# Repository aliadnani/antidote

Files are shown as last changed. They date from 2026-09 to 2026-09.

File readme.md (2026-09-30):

antidote logo

Budget neural amp modelling on a Radxa Cubie A7Z.

---
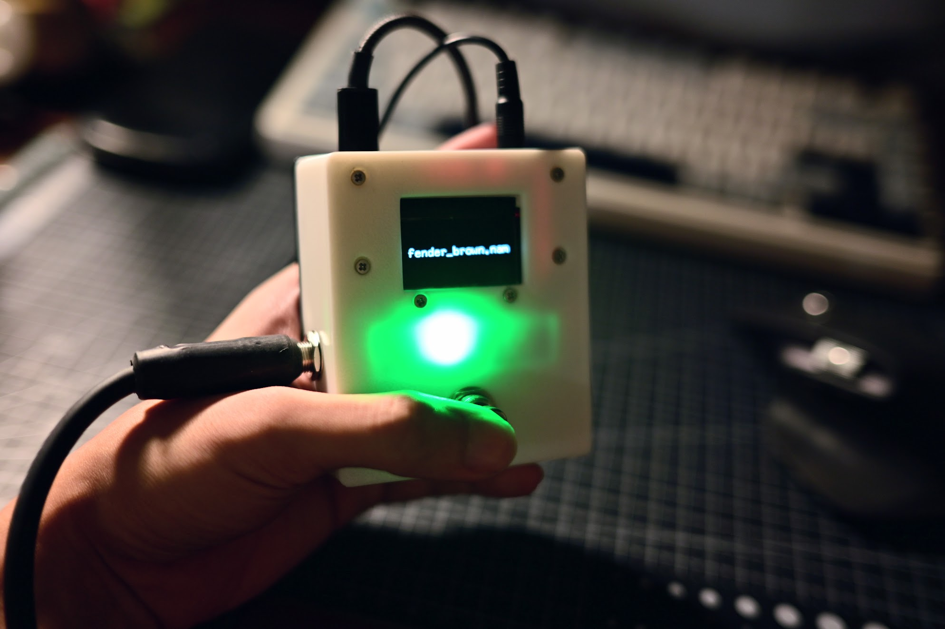
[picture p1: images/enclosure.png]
enclosure


[(sloppy demo video)](https://www.youtube.com/shorts/qqARMGN2HPs)

## What this project does

Neural Amp Modeler (NAM) uses neural networks to model guitar amplifiers from recorded input/output pairs, then reproduces their response on live guitar audio. I want to make a standalone guitar pedal for it.

Rust firmware runs on a Radxa Cubie A7Z Linux SBC. It manages real-time audio capture and playback, including the hot loop that processes each buffer, wraps NAM A2’s C++ DSP library via FFI, and coordinates model loading and the pedal’s peripherals. A custom audio board provides instrument-level input and output.

The end goal is a budget, performant, standalone NAM pedal targetting buffers processed in under 10 ms (ideally under 5 ms) - essentially the threshold for human auditory latency perception.

## This repo

- `src/`: Rust firmware for audio processing, NAM A2 FFI, model loading, and pedal controls.
- `hardware/`: Schematics and PCB design files for the audio board + associated Linux device tree overlays

**Please see this repository as more of a reference design for what's possible and how such a pedal could be built, rather than a polished product.**

## Hardware setup

1. Source a Radxa Cubie A7Z
   - Note: other similar SBCs (like the Pi Zero/OrangePis/etc.) likely **will not work** due to different GPIO header pinouts
2. Have the audio board fabricated with all components populated.
3. Connect the audio board to the SBC via the 40-pin GPIO header.
4. Connect other peripherals to the audio board. In my case, I connected (and built my firmware around):
   - 3.5mm headphone jack for phones
   - 6.35mm TS input for guitar
   - 6.35mm TS output for amp
   - A single footswitch
   - An I2C OLED display (SH1106)
   - A WS2812B LED strip

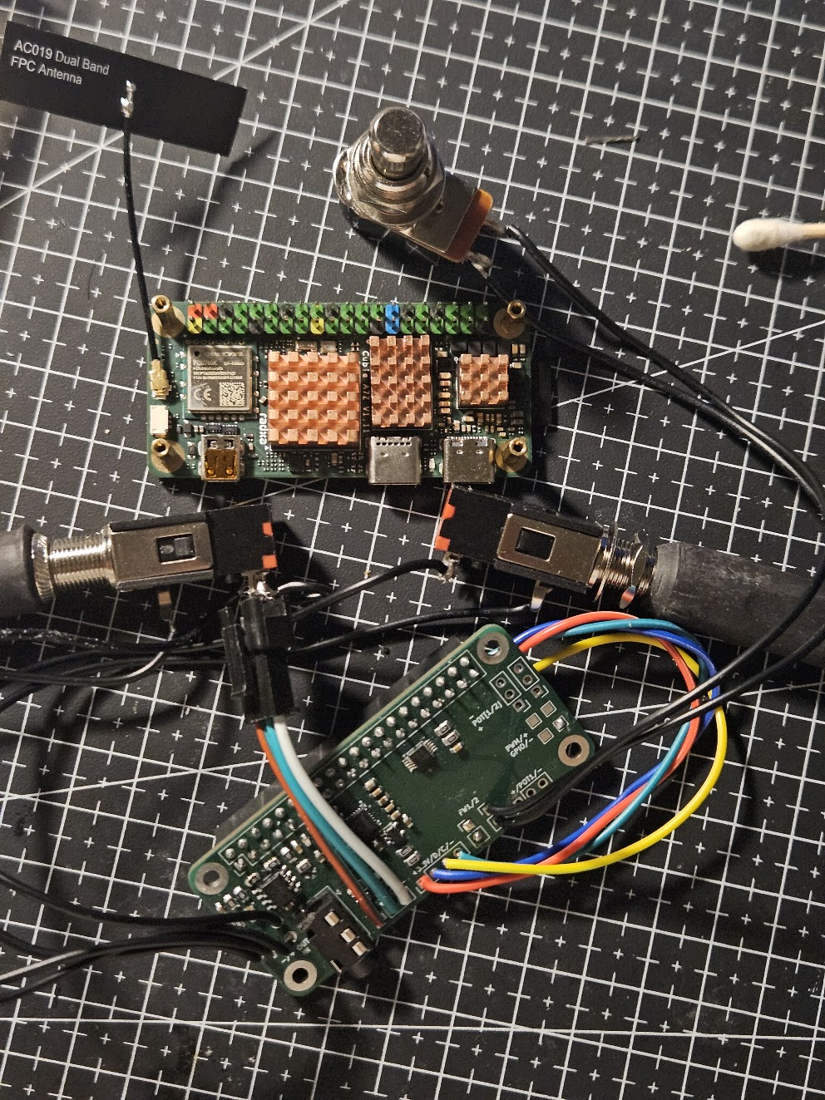
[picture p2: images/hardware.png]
hardware setup


## Firmware setup

1. Flash the SBC with Linux. Official Radxa images or community Armbian images should work fine.
2. Compile and load the driver for the audio board's codec (TAC5112).
   - See the [TI git repository](https://git.ti.com/cgit/lpaa-android-drivers/tac5x1x-linux-driver/?h=tac5x1x_driver) for the source. Check out a branch or tag compatible with your kernel version.
   - Run `make`, then load the kernel module with `insmod` or `modprobe`.
3. Compile and load the device tree overlay for the audio board.
   - The source is `./hardware/tac5112_i2c_i2s_overlay.dts`. Compile it with `dtc` into a `.dtbo` file, then load it via `rsetup`.
4. Configure the codec's ADC, DAC, and capture/playback paths if needed. These commands may be needed:
   ```sh
   sudo amixer -c 0 cset name='ASI_RX_CH1_EN Switch' on
   sudo amixer -c 0 cset name='OUT1x Source' 'DAC Input'
   sudo amixer -c 0 cset name='OUT1x Config' 'Pseudo differential with OUTxM as VCOM'
   sudo amixer -c 0 cset name='OUT1x Driver' 'Headphone'

   sudo amixer -c 0 cset name='ASI_RX_CH2_EN Switch' on
   sudo amixer -c 0 cset name='OUT2x Source' 'DAC Input'
   sudo amixer -c 0 cset name='OUT2x Config' 'Mono Single-ended at OUTxP only'
   sudo amixer -c 0 cset name='OUT2x Driver' 'Line-out'

   sudo amixer -c 0 cset name='ADC1 Config' 'Single-ended'
   sudo amixer -c 0 cset name='ADC1 Common-mode Tolerance' 'AC Coupled with 100mVpp'
   sudo amixer -c 0 cset name='ADC1 Full-Scale' '2/10-VRMS'
   sudo amixer -c 0 cset name='ASI_TX_CH1 Slot' 'Slot0'
   sudo amixer -c 0 cset name='ASI_TX_CH1_EN Capture Switch' on
   sudo amixer -c 0 cset name='ADC1 Digital Capture Volume' 161

   sudo amixer -c 0 cset name='IN1 Source Mux' 'Analog'
   sudo amixer -c 0 cset name='IN2 Source Mux' 'Analog'
   ```
5. Pull in the dependencies, then build the firmware in release mode on the SBC or cross-compile it on a host:
   ```sh
   git submodule update --init --recursive
   cargo build --release
   ```
6. Run the firmware in release mode, passing the directory containing your `.nam` models. If omitted, it uses `resources/`:
   ```sh
   ./target/release/antidote /path/to/nam/files
   # Or:
   cargo run --release -- /path/to/nam/files
   ```

   ```text
   2026-09-25T16:57:33.860341Z  INFO antidote: Starting Antidote.
   2026-09-25T16:57:33.880659Z  INFO antidote::modeller: Loaded NAM A2 model. model_path=resources/fender_brown.nam
   2026-09-25T16:57:33.880875Z  INFO antidote: Starting CPAL.
   2026-09-25T16:57:33.989547Z  INFO antidote: Playing back audio for 500 seconds.
   2026-09-25T16:57:34.898597Z  INFO antidote::audio: Audio errors input_drops=0 output_drops=0 output_underruns=320
   2026-09-25T16:57:35.898842Z  INFO antidote::audio: Audio errors input_drops=0 output_drops=0 output_underruns=320
   2026-09-25T16:57:36.899102Z  INFO antidote::audio: Audio errors input_drops=0 output_drops=0 output_underruns=320
   ...
   ```

## Polishing touches

Once everything is working, some things you can do to make the pedal more usable:

- Add a `systemd` service to run the firmware on boot

### Optimizations

- Disable all unnecessary kernel modules to reduce boot time
  - Stock boots in around ~20 seconds which is actually pretty good - but you can cut another 5-10
- If using a `6.12+` kernel, you can use the play with the `PREEMPT_RT` to reduce latency
- Play around with `mlockall` and `threadirqs`, core pinning/isolation. You can push buffer sizes to around ~24 this way yielding a theorical round-trip latency of ~2ms. 

## Some design goals/notes:

In principle, this project actually builds an entire hardware platform for *any* real-time guitar processing application for Linux SBCs. You can just as easily swap out the the firmware for another that runs say LV2/VST plugins. Though the main focus for this project is a standalone NAM pedal.

---

Built on top of:

- [NAM A2 Source Code](https://github.com/sdatkinson/NeuralAmpModelerCore)
- [NAM A2 Reference](https://www.tone3000.com/guides/nam-a2-the-complete-guide)

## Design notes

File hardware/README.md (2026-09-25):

# Hardware

This directory contains hardware-related files for the Antidote project, including schematics, PCB layouts, and other stuff.

So far we have:
- `antidote-audio-board/`: KiCAD project for the Antidote audio board.
  - See `antidote-audio-board/schematic.pdf` for a PDF of the schematic.
- `tac5112_i2c_i2s_overlay.dts`: The overlay so we can actually bring up the TAC5112 audio codec on our Radxa Cubie A7Z.

## Audio Bring Up on the Radxa Cubie A7Z

Assuming:
- The TAC5112 (daughter-board) is connected via the GPIO headers
- The TAC5112 drivers are compiled and loaded as a module
  - For kernel: 5.15: https://git.ti.com/cgit/lpaa-android-drivers/tac5x1x-linux-driver/log/?h=tac5x1x_driver_k5.15
- The device overlay is compiled and loaded (e.g. via rsetup)

**To play a test tone:**
```bash
# Left channel (for mono headphones - same signal bridged at T/R pins)
# Not sure if `sudo` is needed to be honest
sudo amixer -c 0 cset name='ASI_RX_CH1_EN Switch' on
sudo amixer -c 0 cset name='OUT1x Source' 'DAC Input'
sudo amixer -c 0 cset name='OUT1x Config' 'Pseudo differential with OUTxM as VCOM'
sudo amixer -c 0 cset name='OUT1x Driver' 'Headphone'

# Right channel for instrument line out
sudo amixer -c 0 cset name='ASI_RX_CH2_EN Switch' on
sudo amixer -c 0 cset name='OUT2x Source' 'DAC Input'
sudo amixer -c 0 cset name='OUT2x Config' 'Mono Single-ended at OUTxP only'
sudo amixer -c 0 cset name='OUT2x Driver' 'Line-out'

speaker-test -D hw:0,0 -c 2 -r 48000 -F S32_LE -t sine -f 440
```

**To record audio (+generate spectrogram and log metrics):**
```bash
sudo amixer -c 0 cset name='ADC1 Config' 'Single-ended'
sudo amixer -c 0 cset name='ADC1 Common-mode Tolerance' 'AC Coupled with 100mVpp'
sudo amixer -c 0 cset name='ADC1 Full-Scale' '2/10-VRMS'
sudo amixer -c 0 cset name='ASI_TX_CH1 Slot' 'Slot0'
sudo amixer -c 0 cset name='ASI_TX_CH1_EN Capture Switch' on
sudo amixer -c 0 cset name='ADC1 Digital Capture Volume' 161

sudo amixer -c 0 cset name='IN1 Source Mux' 'Analog'
sudo amixer -c 0 cset name='IN2 Source Mux' 'Analog'

arecord -D hw:0,0 -c 2 -f S32_LE -r 48000 -d 5 retest.wav
sox retest.wav -n stat
sox retest.wav -n spectrogram -o retest_spectro.png
```

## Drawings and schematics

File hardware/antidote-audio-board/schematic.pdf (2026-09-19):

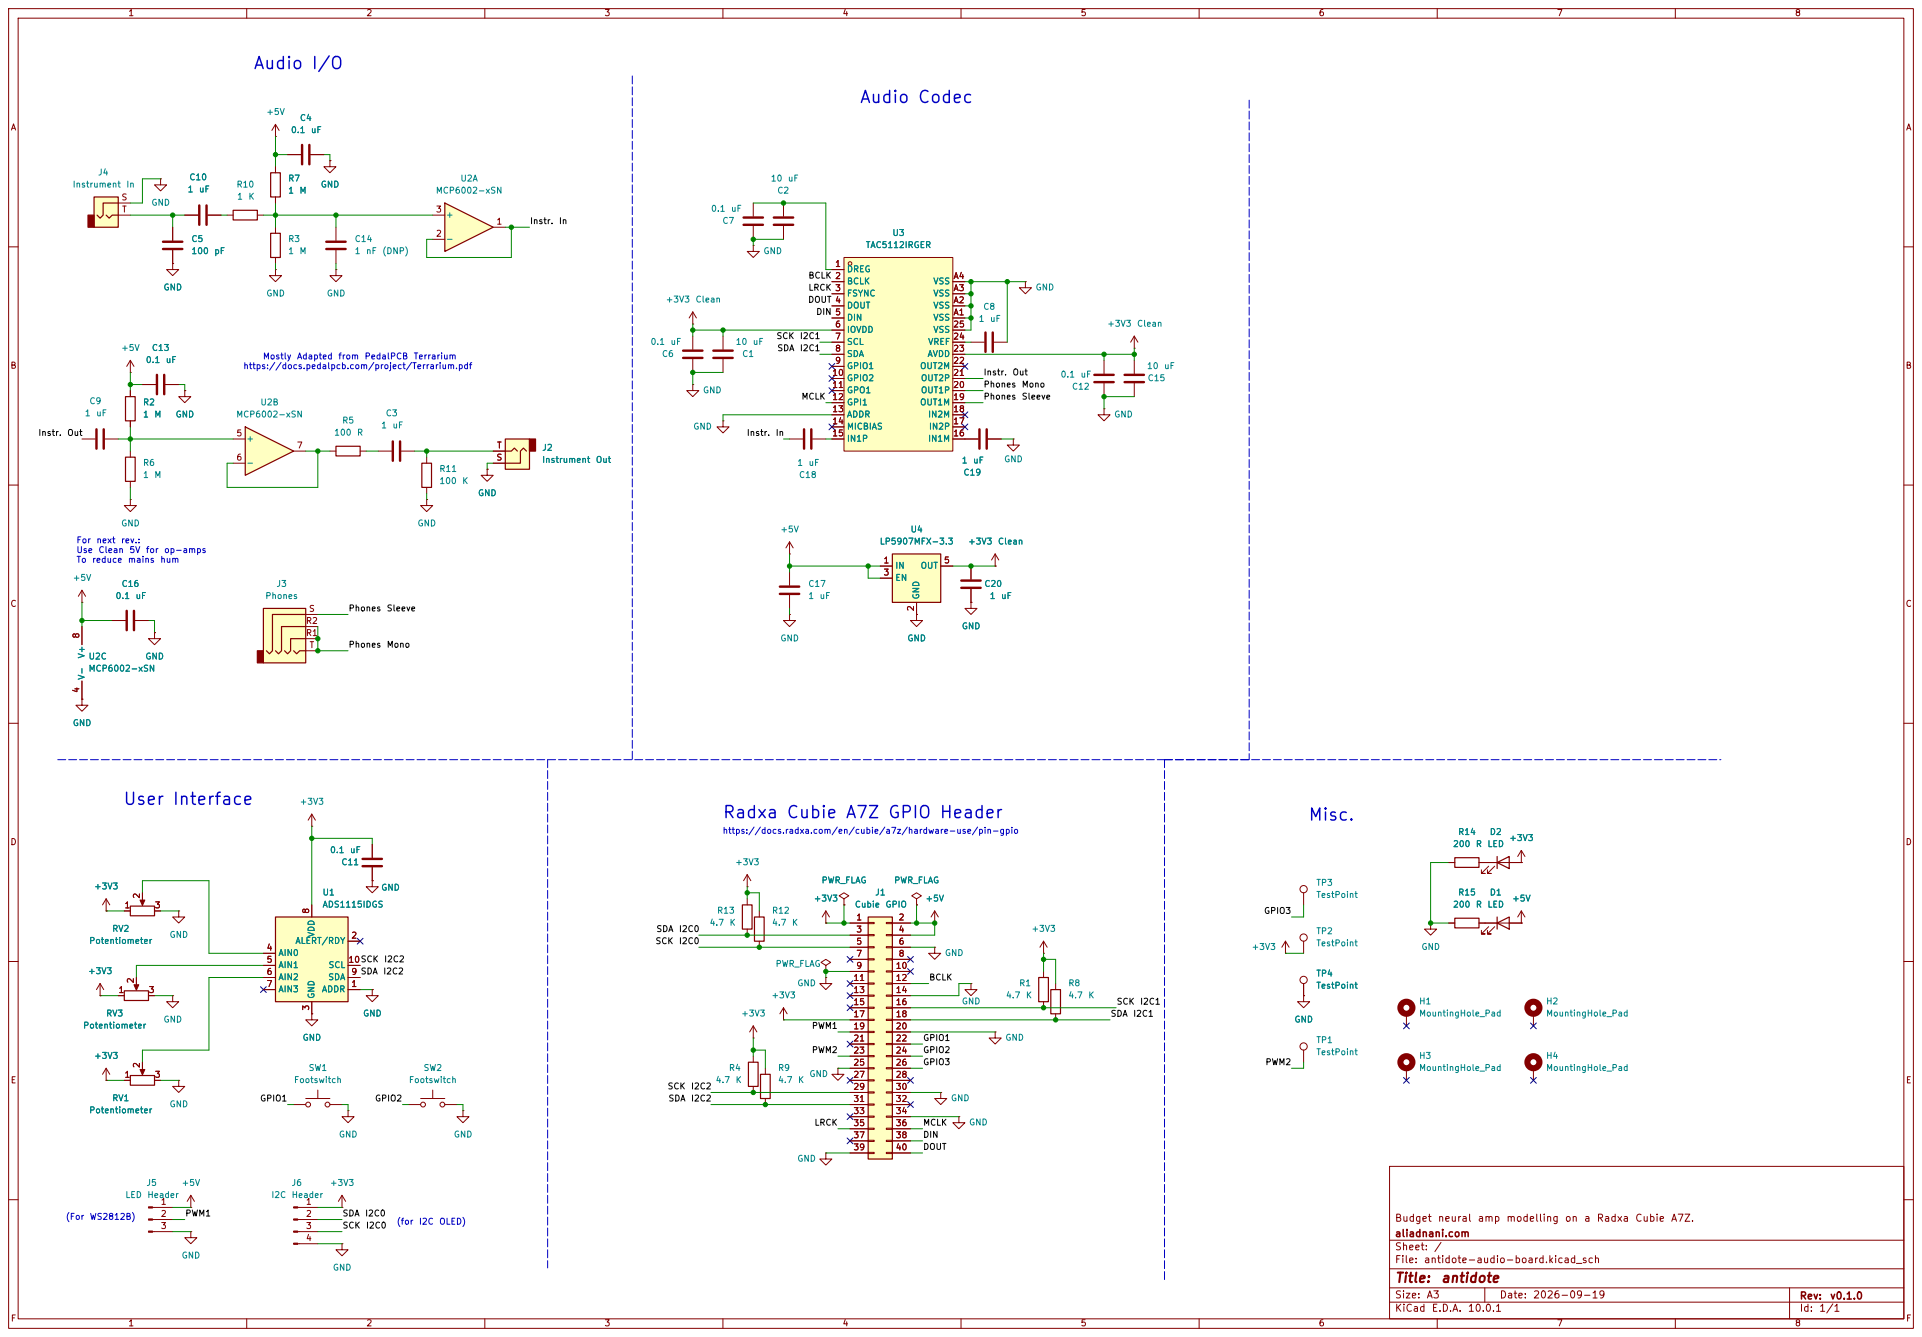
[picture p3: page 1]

Instr. Out Phones Sleeve BCLK

Mostly Adapted from PedalPCB Terrarium
https://docs.pedalpcb.com/project/Terrarium.pdf

For next rev.: Use Clean 5V for op-amps

To reduce mains hum User Interface

Radxa Cubie A7Z GPIO Header

https://docs.radxa.com/en/cubie/a7z/hardware-use/pin-gpio

Budget neural amp modelling on a Radxa Cubie A7Z.
aliadnani.com
Sheet: /
File: antidote-audio-board.kicad_sch
Title: antidote

Size: A3 | Rev: v0.1.0 | F Date: 2026-09-19
KiCad E.D.A. 10.0.1 | Id: 1/1

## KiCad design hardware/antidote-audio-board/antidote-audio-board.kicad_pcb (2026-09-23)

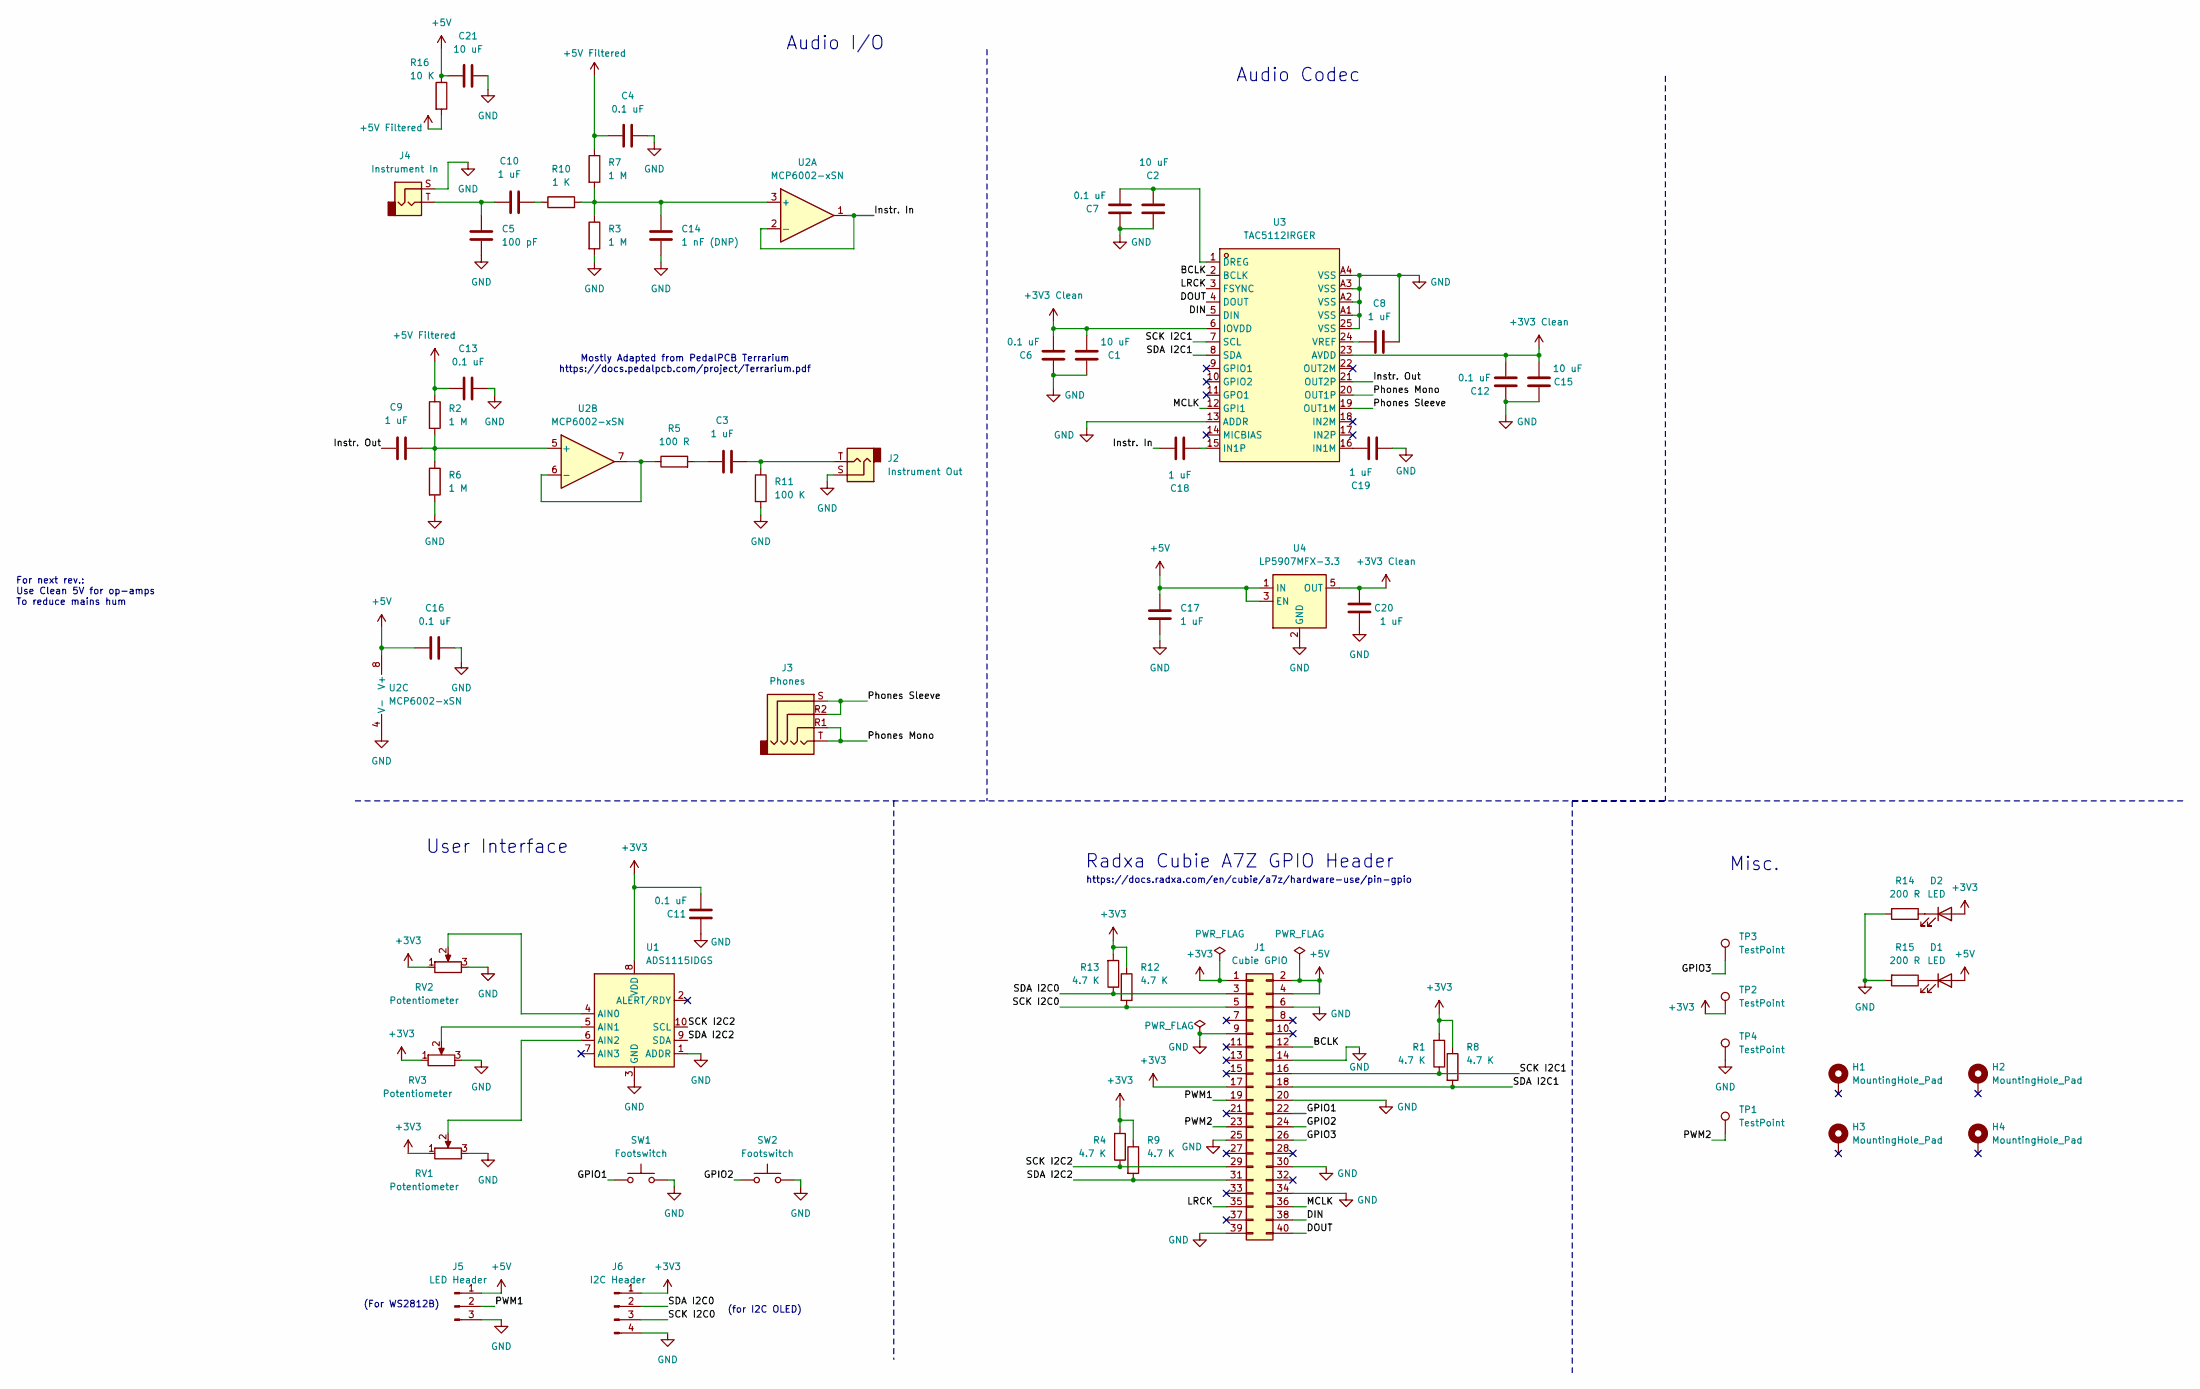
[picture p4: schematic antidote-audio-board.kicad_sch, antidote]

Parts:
C1, C2, C15, C21: 10 uF; C_0603_1608Metric
C3, C8, C9, C10, C17, C18, C19, C20: 1 uF; C_0603_1608Metric
C4, C6, C7, C11, C12, C13, C16: 0.1 uF; C_0603_1608Metric
C5: 100 pF; C_0603_1608Metric
C14: 1 nF (DNP); C_0603_1608Metric
D1, D2: LED; LED_0805_2012Metric
H1, H2, H3, H4: MountingHole_Pad; MountingHole_2.7mm_M2.5_Pad
J1: Cubie GPIO; PinHeader_2x20_P2.54mm_Vertical
J2: Instrument Out; SolderWire-0.5sqmm_1x02_P4.6mm_D0.9mm_OD2.1mm
J3: Phones; Jack_3.5mm_PJ320E_Horizontal
J4: Instrument In; SolderWire-0.5sqmm_1x02_P4.6mm_D0.9mm_OD2.1mm
J5: LED Header; PinHeader_1x03_P2.54mm_Vertical
J6: I2C Header; PinHeader_1x04_P2.54mm_Vertical
R1, R4, R8, R9, R12, R13: 4.7 K; R_0805_2012Metric
R2, R3, R6, R7: 1 M; R_0805_2012Metric
R5: 100 R; R_0805_2012Metric
R10: 1 K; R_0805_2012Metric
R11: 100 K; R_0805_2012Metric
R14, R15: 200 R; R_0805_2012Metric
R16: 10 K; R_0805_2012Metric
RV1, RV2, RV3: Potentiometer; PinHeader_1x03_P2.54mm_Vertical
SW1, SW2: Footswitch; PinHeader_1x02_P2.54mm_Vertical
TP1, TP2, TP3, TP4: TestPoint; TestPoint_Pad_1.5x1.5mm
U1: ADS1115IDGS; TSSOP-10_3x3mm_P0.5mm
U2: MCP6002-xSN; SOIC-8_3.9x4.9mm_P1.27mm
U3: TAC5112IRGER; VQFN-24_L4.0-W4.0-P0.50-BL-EP2.1_1; MPN TAC5112IRGER; LCSC Part C44853692
U4: LP5907MFX-3.3; SOT-23-5

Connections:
+3V3: C11.2, D2.2 (A), J1.1, J1.17, J6.1, R1.2, R4.2, R8.1, R9.1, R12.1, R13.2, RV1.1, RV2.1, RV3.1, TP2.1 (1_1), U1.8 (VDD)
+3V3 Clean: C1.2, C6.2, C12.2, C15.2, C20.1, U3.6 (IOVDD), U3.23 (AVDD), U4.5 (OUT)
+5V: C16.1, C17.1, C21.2, D1.2 (A), J1.2, J1.4, J5.1, R16.1, U2.8 (V+), U4.1 (IN), U4.3 (EN)
+5V Filtered: C4.1, C13.1, R2.1, R7.1, R16.2
/BCLK: J1.12, U3.2 (BCLK)
/DIN: J1.38, U3.5 (DIN)
/DOUT: J1.40, U3.4 (DOUT)
/GPIO1: J1.22, SW1.1
/GPIO2: J1.24, SW2.1
/GPIO3: J1.26, TP3.1 (1_1)
/Instr. In: C18.2, U2.1, U2.2 (-)
/Instr. Out: C9.1, U3.21 (OUT2P)
/LRCK: J1.35, U3.3 (FSYNC)
/MCLK: J1.36, U3.12 (GPI1)
/PWM1: J1.19, J5.2
/PWM2: J1.23, TP1.1 (1_1)
/Phones Mono: J3.R1, J3.T, U3.20 (OUT1P)
/Phones Sleeve: J3.R2, J3.S, U3.19 (OUT1M)
/SCK I2C0: J1.5, J6.3, R12.2
/SCK I2C1: J1.16, R1.1, U3.7 (SCL)
/SCK I2C2: J1.29, R4.1, U1.10 (SCL)
/SDA I2C0: J1.3, J6.2, R13.1
/SDA I2C1: J1.18, R8.2, U3.8 (SDA)
/SDA I2C2: J1.31, R9.2, U1.9 (SDA)
GND: C1.1, C2.1, C4.2, C5.2, C6.1, C7.1, C8.2, C11.1, C12.1, C13.2, C14.2, C15.1, C16.2, C17.2, C19.1, C20.2, C21.1, J1.6, J1.9, J1.14, J1.20, J1.25, J1.30, J1.34, J1.39, J2.S, J4.S, J5.3, J6.4, R3.2, R6.2, R11.2, R14.2, R15.2, RV1.3, RV2.3, RV3.3, SW1.2, SW2.2, TP4.1 (1_1), U1.1 (ADDR), U1.3 (GND), U2.4 (V-), U3.13 (ADDR), U3.25 (VSS), U3.A1 (VSS), U3.A2 (VSS), U3.A3 (VSS), U3.A4 (VSS), U4.2 (GND)
unnamed: C3.1, R5.2
unnamed: C3.2, J2.T, R11.1
unnamed: C5.1, C10.1, J4.T
unnamed: C10.2, R10.1
unnamed: D1.1 (K), R15.1
unnamed: D2.1 (K), R14.1
unnamed: RV2.2, U1.4 (AIN0)
unnamed: RV3.2, U1.5 (AIN1)
unnamed: RV1.2, U1.6 (AIN2)
unnamed: C14.1, R3.1, R7.2, R10.2, U2.3 (+)
unnamed: C9.2, R2.2, R6.1, U2.5 (+)
unnamed: R5.1, U2.6 (-), U2.7
unnamed: C2.2, C7.2, U3.1 (DREG)
unnamed: C19.2, U3.16 (IN1M)
unnamed: C18.1, U3.15 (IN1P)
unnamed: C8.1, U3.24 (VREF)

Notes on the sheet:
Audio Codec
Misc.
Mostly Adapted from PedalPCB Terrarium https://docs.pedalpcb.com/project/Terrarium.pdf
User Interface
Audio I/O
(For WS2812B)
For next rev.: Use Clean 5V for op-amps To reduce mains hum
https://docs.radxa.com/en/cubie/a7z/hardware-use/pin-gpio
Radxa Cubie A7Z GPIO Header
(for I2C OLED)

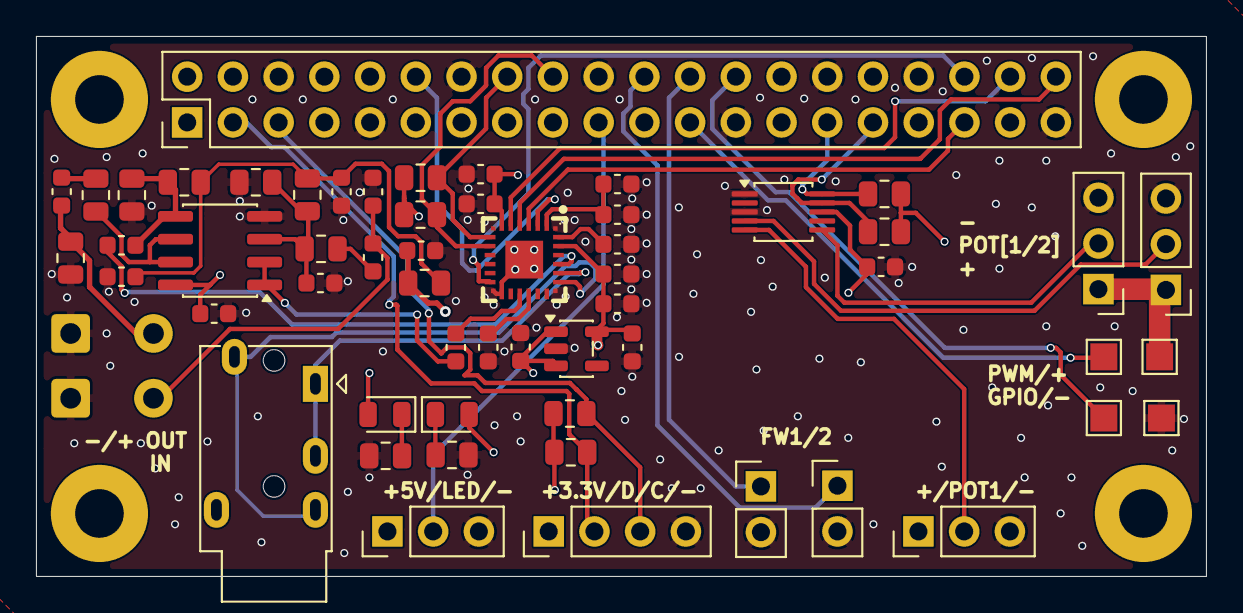
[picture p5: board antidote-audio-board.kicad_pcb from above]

Board: 4 copper layers, 65.0 x 30.0 mm, 62 parts (0 on the bottom side), 41 nets.

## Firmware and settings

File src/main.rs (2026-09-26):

use std::{path::PathBuf, sync::Arc};

use cpal::{
    Stream,
    traits::{DeviceTrait, HostTrait, StreamTrait},
};
use crossbeam::queue::ArrayQueue;
use cxx::UniquePtr;
use tracing::{info, warn};

use crate::{
    audio::{Audio, AudioStats},
    coordinator::Coordinator,
    display::PlatformDisplay,
    input::PlatformInput,
    modeller::Modeller,
    nam_ffi::NamA2Model,
    preprocessor::PreProcessor,
    state::State,
};

pub mod audio;
pub mod coordinator;
pub mod display;
pub mod input;
pub mod modeller;
pub mod nam_ffi;
pub mod preprocessor;
pub mod state;
pub mod tests;

const AUDIO_CHANNELS: usize = 2;
const BUFFER_SIZE: usize = 64;
const QUEUE_CAPACITY: usize = BUFFER_SIZE * 4;
const I32_FULL_SCALE: f32 = 2_147_483_648.0;

const GPIO_CHIP: &str = "/dev/gpiochip1";
const FOOT_SWITCH_RIGHT_LINE: u32 = 5;

const NAM_MODELS_DIR: &str = "resources";

fn main() {
    // Logging
    tracing_subscriber::fmt::init();
    info!("Starting Antidote.");

    let nam_models_dir = match nam_models_dir_from_args() {
        Ok(dir) => dir,
        Err(usage) => {
            eprintln!("{usage}");
            return;
        }
    };

    let state = match State::new(&nam_models_dir) {
        Ok(state) => state,
        Err(error) => {
            warn!(?error, path = %nam_models_dir.display(), "Failed to load NAM profiles");
            return;
        }
    };
    let Some(initial_model_path) = state.current_model().map(|model| model.as_str().to_owned())
    else {
        warn!("No NAM profiles available");
        return;
    };

    // Set up shared audio state
    let (inputs, outputs, audio_stats) = setup_shared_audio_state();

    // Set up inter-thread communication channel for audio commands
    let (command_sender, command_receiver) = crossbeam::channel::unbounded::<audio::AudioCommand>();

    // Set up disposal of retired NAM models on a dedicated thread - their destructors
    let (disposal_tx, disposal_rx) = crossbeam::channel::unbounded::<UniquePtr<NamA2Model>>();
    let model_disposal_handle = setup_model_disposal(disposal_rx);

    // Set up input -> state -> audio command coordination
    let coordinator_thread = setup_coordinator(command_sender, state);

    // Start
    let audio_thread = setup_nam_processing_with_default_model(
        inputs.clone(),
        outputs.clone(),
        command_receiver,
        disposal_tx,
        audio_stats.clone(),
        Some(&initial_model_path),
    );

    // CPAL Audio
    info!("Starting CPAL.");
    let (device, config) = setup_cpal_device_and_config(Some("hw:CARD=sndi2s0,DEV=0"));

    // Set up audio stats reporting thread
    let audio_stats_handle = setup_audio_stats_reporting(audio_stats.clone());

    // Run
    let input_stream = build_input_stream(&device, &config, inputs, audio_stats.clone())
        .expect("Failed to build input stream.");
    let output_stream = build_output_stream(&device, &config, outputs, audio_stats.clone())
        .expect("Failed to build output stream.");

    run_audio(&input_stream, &output_stream);

    std::thread::park();

    drop(input_stream);
    drop(output_stream);

    // Exit and cleanup
    drop(audio_thread);
    drop(coordinator_thread);
    drop(audio_stats_handle);
    drop(model_disposal_handle);

    info!("Exiting Antidote.");
}

fn nam_models_dir_from_args() -> Result<PathBuf, String> {
    let mut args = std::env::args_os();
    let program = args.next().unwrap_or_default();
    let nam_models_dir = args
        .next()
        .map(PathBuf::from)
        .unwrap_or_else(|| PathBuf::from(NAM_MODELS_DIR));

    if args.next().is_some() {
        return Err(format!(
            "Usage: {} [PROFILES_DIR]",
            program.to_string_lossy()
        ));
    }

    Ok(nam_models_dir)
}

fn setup_coordinator(
    command_sender: crossbeam::channel::Sender<audio::AudioCommand>,
    state: State,
) -> Option<std::thread::JoinHandle<()>> {
    let input = match PlatformInput::new(GPIO_CHIP, FOOT_SWITCH_RIGHT_LINE) {
        Ok(input) => input,
        Err(error) => {
            warn!(?error, "No GPIO input available - coordinator not started.");
            return None;
        }
    };

    let display = PlatformDisplay::new();
    let coordinator = Coordinator::new(input, state, command_sender, display);

    Some(std::thread::spawn(move || coordinator.run()))
}

fn setup_shared_audio_state() -> (
    Arc<ArrayQueue<[f32; AUDIO_CHANNELS]>>,
    Arc<ArrayQueue<[f32; AUDIO_CHANNELS]>>,
    Arc<AudioStats>,
) {
    let inputs = Arc::new(ArrayQueue::<[f32; AUDIO_CHANNELS]>::new(QUEUE_CAPACITY));
    let outputs = Arc::new(ArrayQueue::<[f32; AUDIO_CHANNELS]>::new(QUEUE_CAPACITY));
    let audio_stats = Arc::new(AudioStats::new());

    (inputs, outputs, audio_stats)
}

fn setup_nam_processing_with_default_model(
    inputs: Arc<ArrayQueue<[f32; AUDIO_CHANNELS]>>,
    outputs: Arc<ArrayQueue<[f32; AUDIO_CHANNELS]>>,
    command_receiver: crossbeam::channel::Receiver<audio::AudioCommand>,
    disposal_tx: crossbeam::channel::Sender<UniquePtr<NamA2Model>>,
    audio_stats: Arc<AudioStats>,
    default_model_path: Option<&str>,
) -> std::thread::JoinHandle<()> {
    // NAM + Audio subsystem
    let mut modeller = modeller::NamA2ModelModeller::new(disposal_tx);

    if let Some(model_path) = default_model_path {
        modeller
            .load_nam_a2_model(model_path)
            .expect("Could not load NAM A2 model.");
    }

    // USB noise filter experiment
    let preprocessor = PreProcessor::new();

    let mut audio = Audio::new(
        inputs.clone(),
        outputs.clone(),
        modeller,
        BUFFER_SIZE,
        command_receiver,
        audio_stats.clone(),
        Some(preprocessor),
    );

    // Start a new thread to run audio processing loop
    let audio_thread = std::thread::spawn(move || {
        loop {
            audio.tick();
        }
    });

    audio_thread
}

fn setup_cpal_device_and_config(target_device: Option<&str>) -> (cpal::Device, cpal::StreamConfig) {
    let host = cpal::default_host();

    let device = match target_device {
        Some(device_name) => find_device_by_name(&host, device_name).or_else(|| {
            warn!(
                "Could not find device with name '{}', falling back to default input device.",
                device_name
            );
            host.default_input_device()
        }),

        None => host.default_input_device(),
    };

    let device = device.expect("Failed to find a suitable audio input/output device.");

    let config = cpal::StreamConfig {
        channels: AUDIO_CHANNELS as u16,
        sample_rate: 48_000,
        buffer_size: cpal::BufferSize::Fixed(BUFFER_SIZE as u32),
    };

    (device, config)
}

fn find_device_by_name(host: &cpal::Host, device_name: &str) -> Option<cpal::Device> {
    host.devices()
        .expect("Failed to enumerate audio devices.")
        .find(|d| {
            d.description()
                .ok()
                .and_then(|x| x.driver().map(str::to_owned))
                == Some(device_name.into())
        })
}

fn build_input_stream(
    device: &cpal::Device,
    config: &cpal::StreamConfig,
    inputs: Arc<ArrayQueue<[f32; AUDIO_CHANNELS]>>,
    audio_stats: Arc<AudioStats>,
) -> Result<Stream, cpal::Error> {
    device.build_input_stream(
        *config,
        {
            move |data: &[i32], _info: &cpal::InputCallbackInfo| {
                let mut frames = data.chunks_exact(AUDIO_CHANNELS);
                for frame in &mut frames {
                    let frame = [
                        // PCM samples from our I2S lines are i32, so we need to convert them first.
                        frame[0] as f32 / I32_FULL_SCALE,
                        frame[1] as f32 / I32_FULL_SCALE,
                    ];
                    if inputs.force_push(frame).is_some() {
                        audio_stats.record_input_drop();
                    }
                }
            }
        },
        move |error| {
            warn!("Error in input stream: {:?}", error);
        },
        None, // None waits forever to initialize the stream
    )
}

fn build_output_stream(
    device: &cpal::Device,
    config: &cpal::StreamConfig,
    outputs: Arc<ArrayQueue<[f32; AUDIO_CHANNELS]>>,
    audio_stats: Arc<AudioStats>,
) -> Result<Stream, cpal::Error> {
    device.build_output_stream(
        *config,
        move |data: &mut [i32], _info: &cpal::OutputCallbackInfo| {
            let mut frames = data.chunks_exact_mut(AUDIO_CHANNELS);
            for frame in &mut frames {
                let outputs = &outputs;
                let sample = match outputs.pop() {
                    Some([sample, ..]) => sample,
                    None => {
                        audio_stats.record_output_underrun();
                        0.0
                    }
                };
                let sample = (sample * I32_FULL_SCALE) as i32;
                frame[0] = sample;
                frame[1] = sample;
            }
        },
        move |error| {
            warn!("Error in output stream: {:?}", error);
        },
        // None for waiting forever to initialize the stream
        None,
    )
}

fn setup_audio_stats_reporting(audio_stats: Arc<AudioStats>) -> std::thread::JoinHandle<()> {
    std::thread::spawn(move || {
        loop {
            std::thread::sleep(std::time::Duration::from_secs(1));
            audio_stats.report();
        }
    })
}

fn setup_model_disposal(
    disposal_rx: crossbeam::channel::Receiver<UniquePtr<NamA2Model>>,
) -> std::thread::JoinHandle<()> {
    std::thread::spawn(move || {
        while let Ok(retired_model) = disposal_rx.recv() {
            drop(retired_model);
        }
    })
}

fn run_audio(input_stream: &cpal::Stream, output_stream: &cpal::Stream) -> () {
    input_stream.play().unwrap();
    output_stream.play().unwrap();
}

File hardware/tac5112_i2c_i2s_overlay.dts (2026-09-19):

/dts-v1/;
/plugin/;

/ {
	metadata {
		title = "TAC5112 on TWI4 + I2S0 (standalone, replaces i2s0-2ch) V9";
		compatible = "radxa,cubie-a7z";
		category = "misc";
		exclusive = "twi4", "i2s0_plat", "i2s0_mach", "PJ24", "PJ25",
			    "PB4", "PB5", "PB6", "PB7", "PB8";
		description = "Full TAC5112 bring-up: TWI4 control bus (PJ24/PJ25) plus I2S0 audio bus (PB4-PB8) with the codec wired directly into soundcard-mach. Do NOT load alongside sun60iw2p1-i2s0-2ch.dtbo - this overlay replaces it.";
	};
};

&pio {
	twi4_pins_default: twi4-pins-default {
		pins = "PJ24", "PJ25";
		function = "twi4";
		drive-strength = <10>;
		bias-pull-up;
	};

	twi4_pins_sleep: twi4-pins-sleep {
		pins = "PJ24", "PJ25";
		function = "gpio_in";
	};

	i2s0_pins_mclk: i2s0-pins-mclk {
		pins = "PB4";
		function = "i2s0_mclk";
		allwinner,drive = <1>;
		bias-disable;
	};

	i2s0_pins_bclk: i2s0-pins-bclk {
		pins = "PB5";
		function = "i2s0_bclk";
		allwinner,drive = <1>;
		bias-disable;
	};

	i2s0_pins_lrck: i2s0-pins-lrck {
		pins = "PB6";
		function = "i2s0_lrck";
		allwinner,drive = <1>;
		bias-disable;
	};

	i2s0_pins_din0: i2s0-pins-din1 {
		pins = "PB7";
		function = "i2s0_din1";
		allwinner,drive = <1>;
		bias-disable;
	};

	i2s0_pins_dout0: i2s0-pins-dout1 {
		pins = "PB8";
		function = "i2s0_dout1";
		allwinner,drive = <1>;
		bias-disable;
	};

	i2s0_pins_sleep: i2s0-pins-sleep {
		pins = "PB4", "PB5", "PB6", "PB8", "PB7";
		function = "io_disabled";
		allwinner,drive = <1>;
		bias-disable;
	};
};

&twi4 {
	clock-frequency = <400000>;
	pinctrl-0 = <&twi4_pins_default>;
	pinctrl-1 = <&twi4_pins_sleep>;
	pinctrl-names = "default", "sleep";
	status = "okay";

	tac5112: audio-codec@50 {
		compatible = "ti,tac5112";
		reg = <0x50>;
		#sound-dai-cells = <0>;
		ti,vref = <0>;
		ti,micbias-vg = <0>;
	};
};

&i2s0_plat {
	tdm-num = <0>;
	tx-pin = <1>;
	rx-pin = <1>;

	rxfifo-pinmap = <1 1>;
	rxfifo-chmap = <0 1>;

	tx-hub-en;
	rx-sync-en;
	pinctrl-used;
	pinctrl-names = "default", "sleep";
	pinctrl-0 = <&i2s0_pins_mclk &i2s0_pins_bclk &i2s0_pins_lrck
		     &i2s0_pins_din0 &i2s0_pins_dout0>;
	pinctrl-1 = <&i2s0_pins_sleep>;
	status = "okay";
};

&i2s0_mach {
	soundcard-mach,format = "i2s";
	soundcard-mach,slot-num = <2>;
	soundcard-mach,slot-width = <32>;
	soundcard-mach,frame-master = <&i2s0_cpu>;
	soundcard-mach,bitclock-master = <&i2s0_cpu>;
	status = "okay";

	i2s0_cpu: soundcard-mach,cpu {
		sound-dai = <&i2s0_plat>;
		soundcard-mach,pll-fs = <1>;
		soundcard-mach,mclk-fs = <256>;
	};

	soundcard-mach,codec {
		sound-dai = <&tac5112>;
	};
};

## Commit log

2026-09-14 chore: fix typo and log order
    [main.rs]
2026-09-15 chore: fmt & fix
    [main.rs]
2026-09-19 feat: add device overlay for audio codec
2026-09-19 init: add hardware files
    [antidote-audio-board.kicad_pcb, antidote-audio-board.kicad_sch]
2026-09-20 feat: fix schematic issues & document audio bring up
    [antidote-audio-board.kicad_pcb, antidote-audio-board.kicad_sch]
2026-09-22 fix: headphhone jack wiring is wrong
    [antidote-audio-board.kicad_pcb]
2026-09-22 feat: (untested) seperate audio thread for NAM processing
2026-09-22 feat: many many optimizations - 56 sample buffer now possible
2026-09-23 feat: add rc tap to clean op-amp noise
    [antidote-audio-board.kicad_pcb, antidote-audio-board.kicad_sch]
2026-09-23 debug: switch gpio library
2026-09-23 fix: too many xruns
    [main.rs]
2026-09-23 feat: off thread model loading
2026-09-24 ai: experiment with usb noise filtering
    [main.rs]
2026-09-25 fix: button inputs and flipped screen
    [linux.rs]
2026-09-25 ai/revert: go back to old non-kernel debounces
    [linux.rs]
2026-09-25 ai: fix long press
    [linux.rs]
2026-09-25 ai: fix buttons
2026-09-25 un-ai: desloppify brittle rising/falling edge button detection and just poll
2026-09-25 fix: remove missing as input
    [linux.rs]
2026-09-26 fix: streams dropped immediately after starting
    [main.rs]
2026-09-26 fix: immediately dropped streams again
    [main.rs]
2026-09-26 fix: immediately dropped streams again (2)
    [main.rs]
2026-09-30 docs: tighten english
